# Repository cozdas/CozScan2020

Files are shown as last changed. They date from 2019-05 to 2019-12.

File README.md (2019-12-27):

# CozScan2020



This is a do-it-yourself 20-channel solid-state scanner card compatible with Keithley 2000-SCAN-20 and thus should work with Keithley 2000, 2001, 2002, 2010 and DMM6500 bench multimeters. **Currently this design is tested only on DMM6500.**

|**== Warning ==**|
|-|
| **If you decide to build and/or use this card do it at your own risk. I do not guarantee that this design works properly and I can't guarantee that using this won't result any damages to the equipment or won't cause injury. Electrical or thermal limits of this design are unknown/unspecified. So please make sure that you understand the design before attempting to build and/or use it.**|

## History behind the project
I've always had a multimeter since highschool, where I studied electronics. But all of them were handheld devices. So recently I decided to get a bench multimeter and Keithley DMM6500 seemed like a perfect choice for my needs. I liked the scanner card support which makes the unit work as a small data acqusition system. I bought a used 2000-SCAN card from eBay and it worked perfectly, I was able to record multiple quantities over long time spans and analyse their dependencies (such as tempco measurement ). But there was one problem: the original SCAN-2000 card has mechanical relays and they are loud therefore logging multiple channels overnight in my office, which is near our bedroom, was an annoying dripping-tap simulator. So I decided to build myself a silent solid-state version.

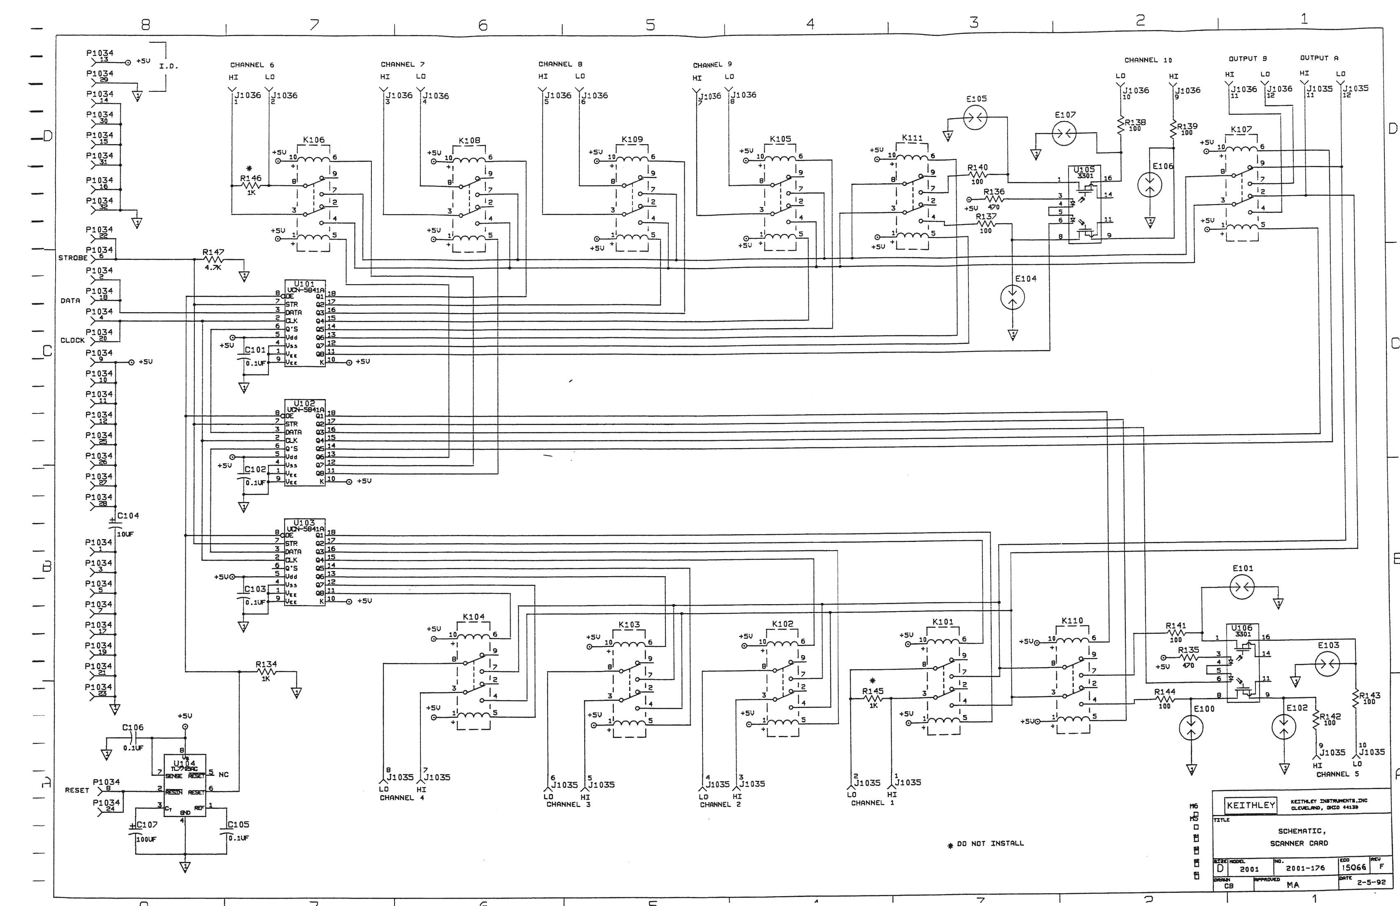
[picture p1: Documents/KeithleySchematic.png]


The original Keithley SCAN-2000 card has a very basic design: few serial-to-parallel shift registers and bunch of bi-stable (latching) mechanical relays. The control signal from the DMM has 3 lines: clock, data and strobe. The card's manual has the full schematic; by looking at the schematic you can determine which bit does what. After realizing that the 20-channel scan-2020 card uses the same interface and the same basic circuit design, I decided to implement a 20 channel card, the more the merrier. The DMM determines the installed card type using the ID pins (13 and 29) on the connector. 

## Reverse Engineering the Communication

The schematic shows all the connections and logic but doesn't tell much about the timings and how the DMM drives the relays. For that reason I just sniffed the clock, data and strobe lines both in scan-2000 and scan-2020 mode using both my oscillascope and a cheap logic analyser. You can find the [logic analyser logs](Documents/LogicAnalyserLogs/) in the Documents folder. You can open the files with [Saleae Logic software](https://www.saleae.com/downloads/)

Here are the key timing figures:

* Clock: 100kHz, %33 duty
* Data: 10us, centered around clock pulse
* Relay coil current duration: 4ms
* Strobe Pulse: 3.333ms
* Channel off to channel on: ~1.7ms

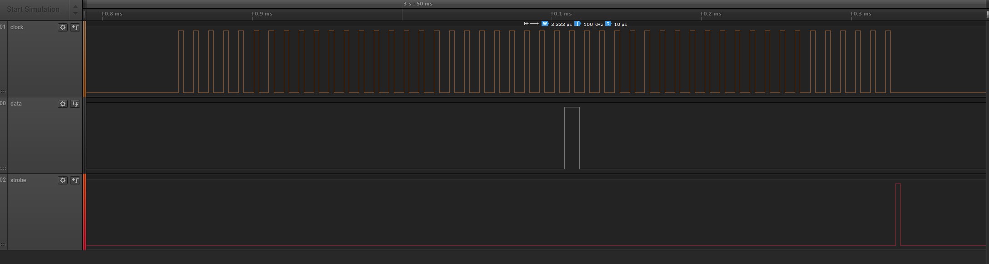
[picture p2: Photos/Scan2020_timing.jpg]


## Circuit Design

Initially I was planning to replicate the same circuit, using the same or similar components. One problem with that approach was that unlike the mechanical latching relays, the solid state relays are not latching thus I had add latches to the circuit so that the turned on relay stays on even after the DMM sets the coil off. This quickly increased the number of compoments required for the board. 

So instead of following the same design with primitive logic elements, I decided to switch to a microcontroller + software solution. I needed a cheap microcontroller with at least 25 IO pins (20 outputs for the channels, 2 outputs for directing the upper channels either to input or to sense and 3 input pins for DMM communication). The most convenient solution turned out to be using a cheap arduino micro compatible board with ATmega32U4 MCU. One minor problem with that board was that only 24 of the 26 IO pins of the ATmega32U4 were exposed on the board pinout and that was unfortunately 1 short of what I needed. But after checking the Arduino Micro schematic I saw that it's easy to pull a wire from the TX led to one of the unused pins, exposing PD5 signal and thus increasing the IO pin count to needed 25.

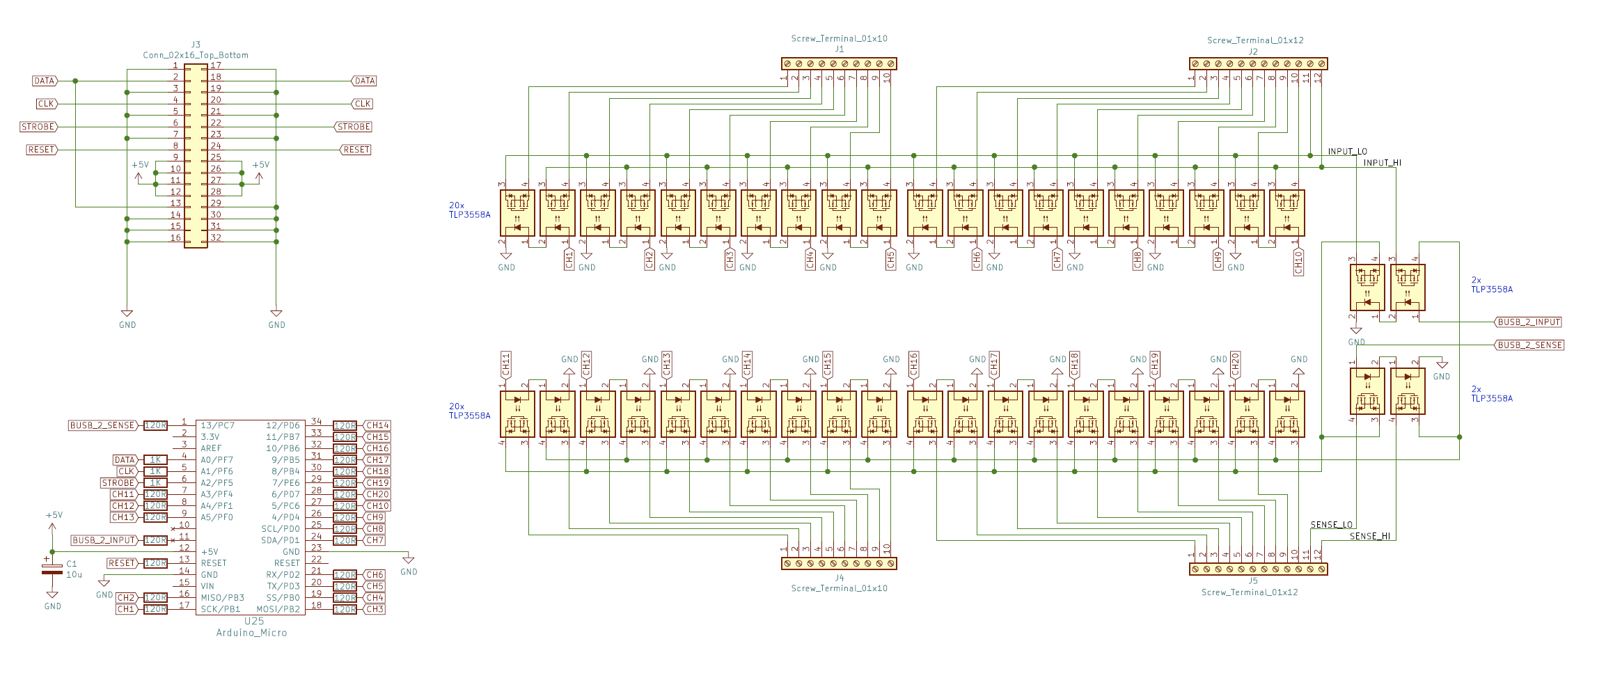
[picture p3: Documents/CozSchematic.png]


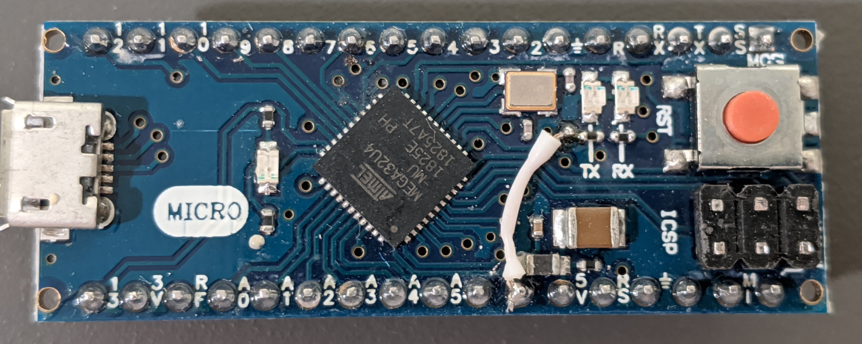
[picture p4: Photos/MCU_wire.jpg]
WIRE PIC


One gothca you need to be careful while choosing a MCU board is that some boards with certain bootloader firmware (Such as Arduino Uno) will blink the LED while booting. Make sure that the board+firmware you have doesn't have this behavior.

As SSRs I picked Toshiba TLP3558A as it seemed to be at the sweet spot of on-resistance, price and leakage current. It might not be the best choice, feel free to modify that to your taste.

## PCB Design
This is a "Do-It-Yourself as much as you can" project, thus I wanted to make my own PCB. Since I can't do through-hole plating I designed the layout such that the pins of the components are used as the vias and for this reason I preferred through-hole components. A more tidy and even compact layout with SMD components should be possible if the PCB will be manufactured professionally. First I tried to use Eagle CAD, which I was already familiar with, but the free version is not supporting boards this big. Internets(tm) seems to agree on the KiCAD as one of the best options, thus I learned how to use KiCAD and used it for this project.

You can find the KiCAD project files in the [KiCAD folder](KiCad/). Since this is my very first KiCAD design, I'm sure that there are some mistakes/not-so-correct things I've done. Let me know if you spot any.

## Software

My first attemp was an interrupt-driven software but it was behaving erratically. After a short debugging session I found the source of the problem: the MCU was not fast enough and was missing the clocks. I tried to optimize the code as much as I can with some bit-magic etc but it was still missing the clocks. So I decided to switch to active polling mode and disable the inturrupts completely, making the system more suitable for a realtime application. Polling the clock edges in an active loop indeed worked properly and it was fast enough that I was able to squeeze in some sanity checking routine to the code; making sure that we collected correct number of bits before the strobe, only one channel is connected to the input or sense terminals etc.

The Arduino studio source is located in the [Arduino](Arduino/) folder.

## Bill of Materials
- DMM Connector: 1x [Molex 85050](https://www.digikey.com/product-detail/en/molex/0850500000/WM20488-ND/2790645)
- Solid State Relay: 24x [Toshiba TLP3558A](https://www.digikey.com/product-detail/en/toshiba-semiconductor-and-storage/TLP3558A-F/TLP3558A-F-ND/8539925)
- Cable Terminal Blocks: 
  - 12 Pos: 2x [Phoenix Contact 1869318](https://www.digikey.com/product-detail/en/phoenix-contact/1869318/277-6361-ND/349230)
  - 10 Pos: 2x [Phoenix Contact 1869295](https://www.digikey.com/product-detail/en/phoenix-contact/1869295/277-6063-ND/349229)
- Controller: 1x [Arduino Micro](https://store.arduino.cc/usa/arduino-micro) (or [a clone](https://www.amazon.com/dp/B00J1X5B7Y))
- Resistors
  - 22x 120 Ohm 1/4W
  - 3x 1 kOhm 1/4W
- Capacitor: 1uF 16V
- PCB: 205mm x 70mm x 1.5mm, dual-sided

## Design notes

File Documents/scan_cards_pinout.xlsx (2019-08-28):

keithley pin # | Header Pin # | name | 2000-172 (my board) | 2001-176 revF | 2000-SCAN-20 | 2001-TSCAN | 1801 nanovolt preamp | wire
1 |  |  | GND | GND | GND | GND | GND | blue
2 |  | DATA | DATA | DATA | DATA | DATA | DATA | blue/white
3 |  |  | GND | GND | GND | GND | GND
4 |  | CLK | CLK | CLK | CLK | CLK | CLK | brown/white
5 |  |  | GND | GND | GND | GND | GND
6 |  | STROBE | STROBE | STROBE | STROBE | STROBE | STROBE | brown
7 |  |  | GND | GND | GND | GND | GND
8 |  | RESET | RESET | RESET | RESET | RESET | RESET | orange/white
9 |  |  | 5V | 5V | 5V | 5V | 5V
10 |  |  | 5V | 5V | 5V | 5V | 5V | orange
11 |  |  | 5V | 5V | 5V | 5V | 5V
12 |  |  | 5V | 5V | 5V | 5V | 5V
13 |  | ID | 5V | 5V | DATA | 5V | 5V | green
14 |  |  | GND | GND | GND | GND | SCL
15 |  |  | GND | GND | GND | GND | SDA
16 |  |  | GND | GND | GND | GND | GND
17 |  |  | GND | GND | GND | GND | GND
18 |  | DATA | DATA | DATA | DATA | DATA | DATA
19 |  |  | GND | GND | GND | GND | GND
20 |  | CLK | CLK | CLK | CLK | CLK | CLK
21 |  |  | GND | GND | GND | GND | GND
22 |  | STROBE | STROBE | STROBE | STROBE | STROBE | STROBE
23 |  |  | GND | GND | GND | GND | GND
24 |  | RESET | RESET | RESET | RESET | RESET | RESET
25 |  |  | 5V | 5V | 5V | 5V | 5V
26 |  |  | 5V | 5V | 5V | 5V | 5V
27 |  |  | 5V | 5V | 5V | 5V | 5V
28 |  |  | 5V | 5V | 5V | 5V | 5V
29 |  | ID | GND | GND | GND | GND | GND | green/white
30 |  |  | GND | GND | GND | GND | GND
31 |  |  | GND | GND | GND | GND | GND
32 |  |  | GND | GND | GND | GND | GND
Note: keithley numbers pins sequentially one row and moves on on the other row. Eagle uses row1, row2, row1, row2 order.

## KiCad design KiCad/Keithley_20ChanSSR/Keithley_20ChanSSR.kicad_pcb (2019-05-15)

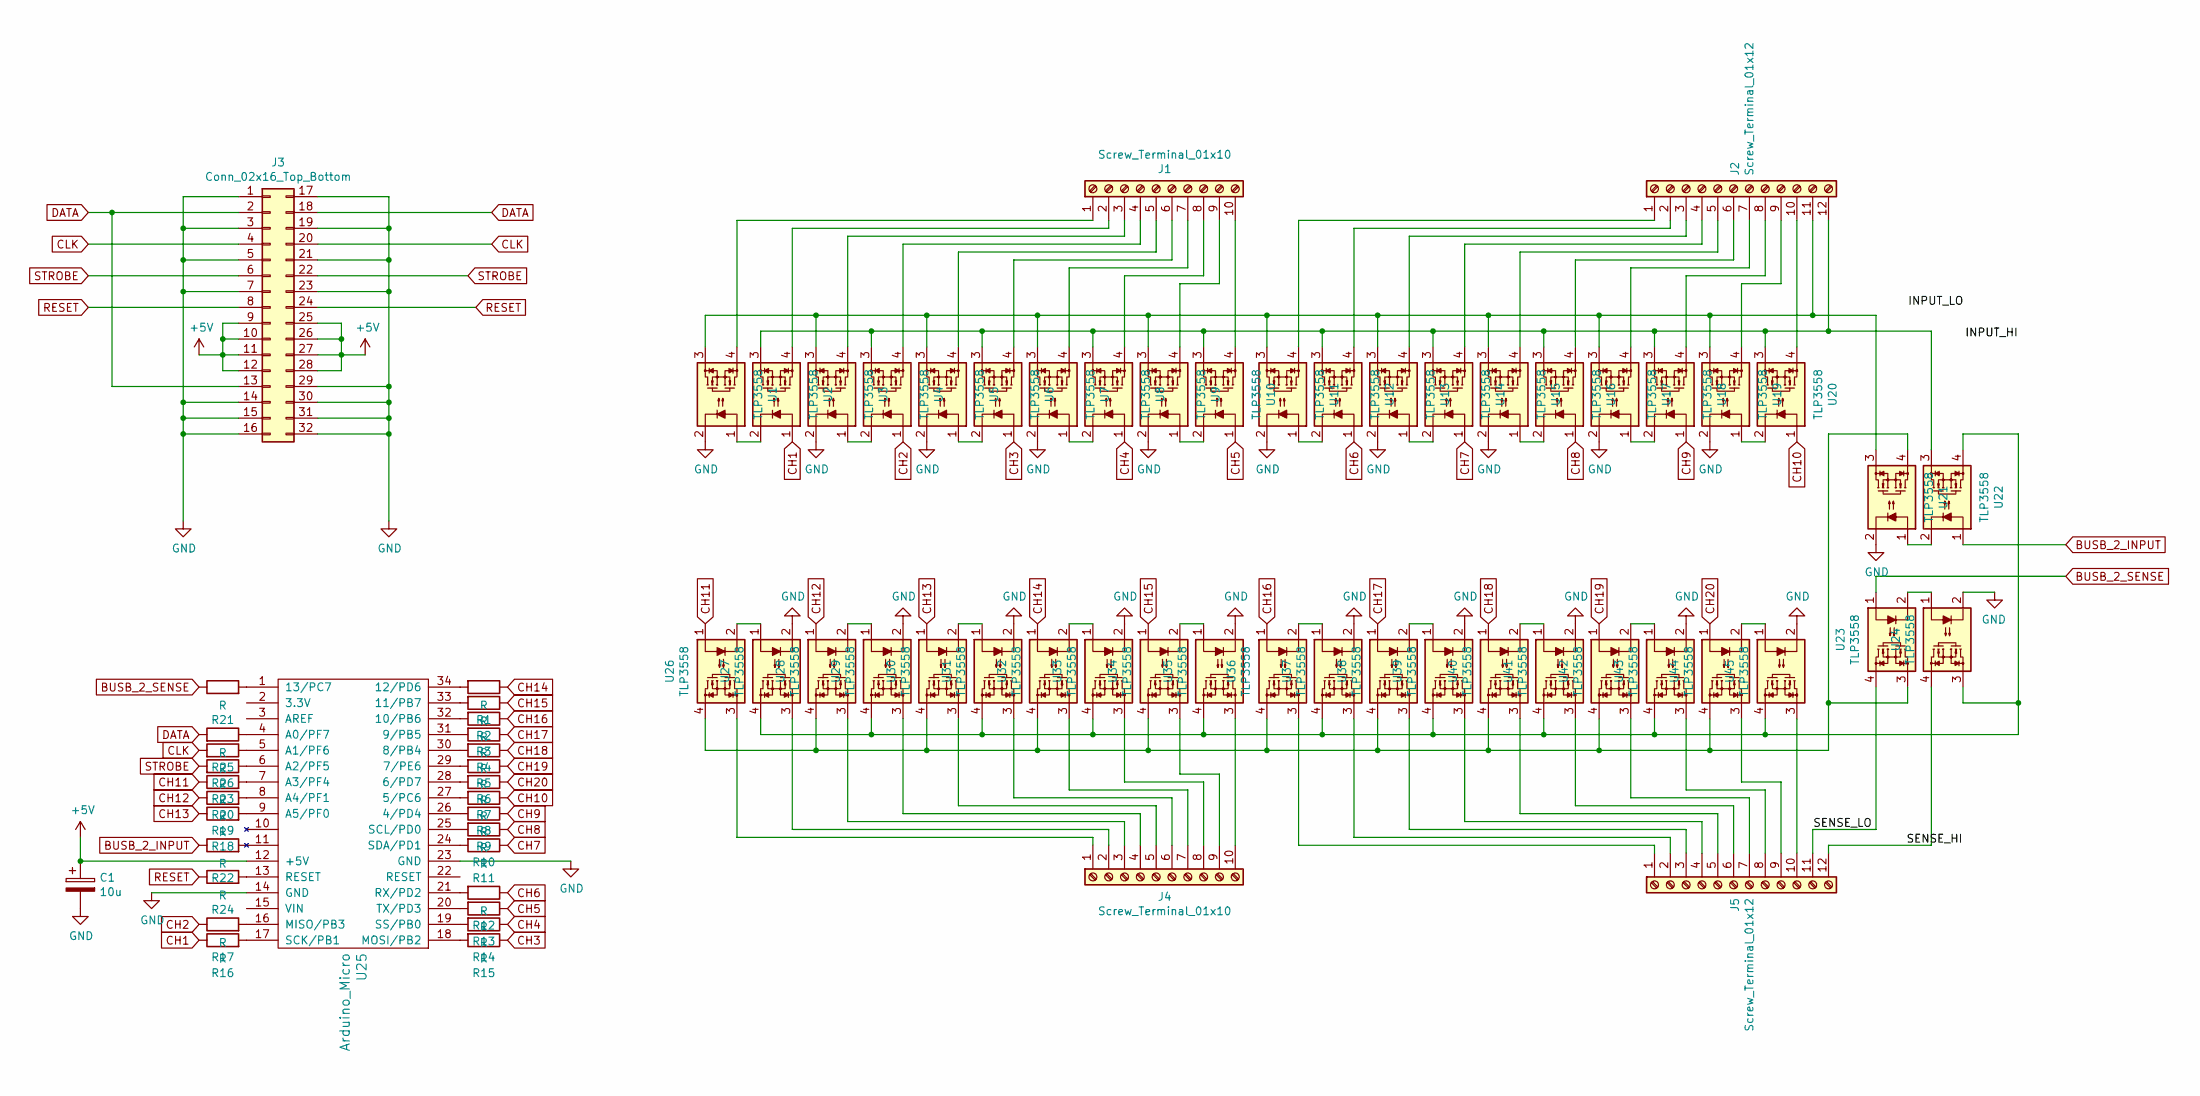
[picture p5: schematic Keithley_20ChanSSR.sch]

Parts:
C1: 10u; CP_EIA-6032-20_AVX-F
J1, J4: Screw_Terminal_01x10; TerminalBlock_Phoenix_MKDS-3-10-5.08_1x10_P5.08mm_Horizontal
J2, J5: Screw_Terminal_01x12; TerminalBlock_Phoenix_MKDS-1,5-12-5.08_1x12_P5.08mm_Horizon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
J3: Conn_02x16_Top_Bottom; DIN41612_B2_2x16_Horizontal
R1, R2, R3, R4, R5, R6, R7, R8, R9, R10, R11, R12, R13, R14, R15, R16, R17, R18, R19, R20, R21, R22, R23, R24, R25, R26: R; R_Axial_DIN0207_L6.3mm_D2.5mm_P10.16mm_Horizontal
U1, U2, U3, U4, U5, U6, U7, U8, U9, U10, U11, U12, U13, U14, U15, U16, U17, U18, U19, U20, U21, U22, U23, U24, U26, U27, U28, U29, U30, U31, U32, U33, U34, U35, U36, U37, U38, U39, U40, U41, U42, U43, U44, U45: TLP3558; DIP-4_W7.62mm_LongPads_coz
U25: Arduino_Micro; Arduino_Micro_Socket_coz

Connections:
+5V: C1.1, J3.9, J3.10, J3.11, J3.12, J3.25, J3.26, J3.27, J3.28, U25.12 (+5V)
/SENSE_LO: J5.11, U23.4
BUSB_2_INPUT: R22.1, U22.1
BUSB_2_SENSE: R21.1, U23.1
CH1: R16.1, U2.1
CH2: R17.1, U4.1
CH3: R15.1, U6.1
CH4: R14.1, U8.1
CH5: R13.1, U10.1
CH6: R12.1, U12.1
CH7: R11.1, U14.1
CH8: R10.1, U16.1
CH9: R9.1, U18.1
CH10: R8.1, U20.1
CH11: R20.1, U26.1
CH12: R19.1, U28.1
CH13: R18.1, U30.1
CH14: R1.1, U32.1
CH15: R2.1, U34.1
CH16: R3.1, U36.1
CH17: R4.1, U38.1
CH18: R5.1, U40.1
CH19: R6.1, U42.1
CH20: R7.1, U44.1
CLK: J3.4, J3.20, R26.2
DATA: J3.2, J3.13, J3.18, R25.2
GND: C1.2, J3.1, J3.3, J3.5, J3.7, J3.14, J3.15, J3.16, J3.17, J3.19, J3.21, J3.23, J3.29, J3.30, J3.31, J3.32, U1.2, U3.2, U5.2, U7.2, U9.2, U11.2, U13.2, U15.2, U17.2, U19.2, U21.2, U24.2, U25.14 (GND), U25.23 (GND), U27.2, U29.2, U31.2, U33.2, U35.2, U37.2, U39.2, U41.2, U43.2, U45.2
unnamed: J1.1, U1.4
unnamed: J1.2, U2.4
unnamed: J1.3, U3.4
unnamed: J1.4, U4.4
unnamed: J1.5, U5.4
unnamed: J1.6, U6.4
unnamed: J1.7, U7.4
unnamed: J1.8, U8.4
unnamed: J1.9, U9.4
unnamed: J1.10, U10.4
unnamed: J2.1, U11.4
unnamed: J2.2, U12.4
unnamed: J2.3, U13.4
unnamed: J2.4, U14.4
unnamed: J2.5, U15.4
unnamed: J2.6, U16.4
unnamed: J2.7, U17.4
unnamed: J2.8, U18.4
unnamed: J2.9, U19.4
unnamed: J2.10, U20.4
unnamed: J2.11, U1.3, U3.3, U5.3, U7.3, U9.3, U11.3, U13.3, U15.3, U17.3, U19.3, U21.3
unnamed: J2.12, U2.3, U4.3, U6.3, U8.3, U10.3, U12.3, U14.3, U16.3, U18.3, U20.3, U22.3
unnamed: J4.1, U26.3
unnamed: J4.2, U27.3
unnamed: J4.3, U28.3
unnamed: J4.4, U29.3
unnamed: J4.5, U30.3
unnamed: J4.6, U31.3
unnamed: J4.7, U32.3
unnamed: J4.8, U33.3
unnamed: J4.9, U34.3
unnamed: J4.10, U35.3
unnamed: J5.1, U36.3
unnamed: J5.2, U37.3
unnamed: J5.3, U38.3
unnamed: J5.4, U39.3
unnamed: J5.5, U40.3
unnamed: J5.6, U41.3
unnamed: J5.7, U42.3
unnamed: J5.8, U43.3
unnamed: J5.9, U44.3
unnamed: J5.10, U45.3
unnamed: J5.12, U24.4
unnamed: R1.2, U25.34 (12/PD6)
unnamed: R2.2, U25.33 (11/PB7)
unnamed: R3.2, U25.32 (10/PB6)
unnamed: R4.2, U25.31 (9/PB5)
unnamed: R5.2, U25.30 (8/PB4)
unnamed: R6.2, U25.29 (7/PE6)
unnamed: R7.2, U25.28 (6/PD7)
unnamed: R8.2, U25.27 (5/PC6)
unnamed: R9.2, U25.26 (4/PD4)
unnamed: R10.2, U25.25 (SCL/PD0)
unnamed: R11.2, U25.24 (SDA/PD1)
unnamed: R12.2, U25.21 (RX/PD2)
unnamed: R13.2, U25.20 (TX/PD3)
unnamed: R14.2, U25.19 (SS/PB0)
unnamed: R15.2, U25.18 (MOSI/PB2)
unnamed: R16.2, U25.17 (SCK/PB1)
unnamed: R17.2, U25.16 (MISO/PB3)
unnamed: R18.2, U25.9 (A5/PF0)
unnamed: R19.2, U25.8 (A4/PF1)
unnamed: R20.2, U25.7 (A3/PF4)
unnamed: R21.2, U25.1 (13/PC7)
unnamed: R22.2, U25.11
unnamed: R23.1, U25.6 (A2/PF5)
unnamed: R24.2, U25.13 (RESET)
unnamed: R25.1, U25.4 (A0/PF7)
unnamed: R26.1, U25.5 (A1/PF6)
unnamed: U1.1, U2.2
unnamed: U3.1, U4.2
unnamed: U5.1, U6.2
unnamed: U7.1, U8.2
unnamed: U9.1, U10.2
unnamed: U11.1, U12.2
unnamed: U13.1, U14.2
unnamed: U15.1, U16.2
unnamed: U17.1, U18.2
unnamed: U19.1, U20.2
unnamed: U21.1, U22.2
unnamed: U21.4, U23.3, U26.4, U28.4, U30.4, U32.4, U34.4, U36.4, U38.4, U40.4, U42.4, U44.4
unnamed: U22.4, U24.3, U27.4, U29.4, U31.4, U33.4, U35.4, U37.4, U39.4, U41.4, U43.4, U45.4
unnamed: U23.2, U24.1
unnamed: U26.2, U27.1
unnamed: U28.2, U29.1
unnamed: U30.2, U31.1
unnamed: U32.2, U33.1
unnamed: U34.2, U35.1
unnamed: U36.2, U37.1
unnamed: U38.2, U39.1
unnamed: U40.2, U41.1
unnamed: U42.2, U43.1
unnamed: U44.2, U45.1
RESET: J3.8, J3.24, R24.1
STROBE: J3.6, J3.22, R23.2

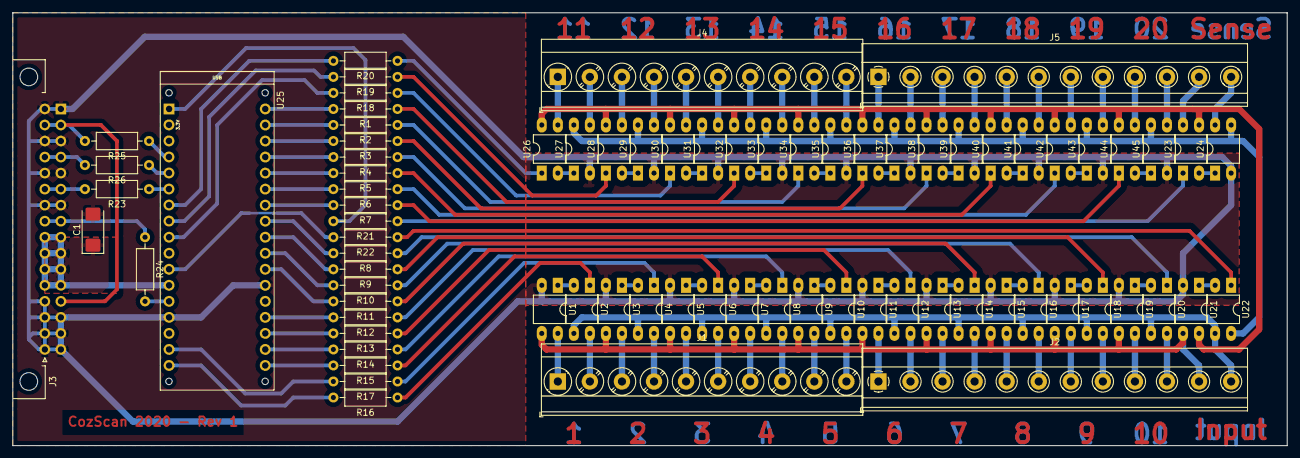
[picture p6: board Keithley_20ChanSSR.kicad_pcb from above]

Board: 2 copper layers, 201.9 x 68.6 mm, 77 parts (0 on the bottom side), 122 nets.

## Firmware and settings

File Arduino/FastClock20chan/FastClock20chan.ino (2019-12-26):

//===================
// CozScan2020
//===================

/* *****
BSD 3-Clause License

Copyright (c) 2019, Cuneyt Ozdas
All rights reserved.

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
1. Redistributions of source code must retain the above copyright notice, this
   list of conditions and the following disclaimer.

2. Redistributions in binary form must reproduce the above copyright notice,
   this list of conditions and the following disclaimer in the documentation
   and/or other materials provided with the distribution.

3. Neither the name of the copyright holder nor the names of its
   contributors may be used to endorse or promote products derived from
   this software without specific prior written permission.

THIS SOFTWARE IS PROVIDED BY THE COPYRIGHT HOLDERS AND CONTRIBUTORS "AS IS"
AND ANY EXPRESS OR IMPLIED WARRANTIES, INCLUDING, BUT NOT LIMITED TO, THE
IMPLIED WARRANTIES OF MERCHANTABILITY AND FITNESS FOR A PARTICULAR PURPOSE ARE
DISCLAIMED. IN NO EVENT SHALL THE COPYRIGHT HOLDER OR CONTRIBUTORS BE LIABLE
FOR ANY DIRECT, INDIRECT, INCIDENTAL, SPECIAL, EXEMPLARY, OR CONSEQUENTIAL
DAMAGES (INCLUDING, BUT NOT LIMITED TO, PROCUREMENT OF SUBSTITUTE GOODS OR
SERVICES; LOSS OF USE, DATA, OR PROFITS; OR BUSINESS INTERRUPTION) HOWEVER
CAUSED AND ON ANY THEORY OF LIABILITY, WHETHER IN CONTRACT, STRICT LIABILITY,
OR TORT (INCLUDING NEGLIGENCE OR OTHERWISE) ARISING IN ANY WAY OUT OF THE USE
OF THIS SOFTWARE, EVEN IF ADVISED OF THE POSSIBILITY OF SUCH DAMAGE.
***** */


// Notes:
// ==========
// using interrupts was too slow, the clock ISR was
// totally missing the data. Actively waiting the rising clock
// edge is much faster, now the data is properly sampled before the falling edge
// of the clock


//Arduino DATA pins on the Micro board
//D0 = pin 20  RX
//D1 = pin 21  TX
//D2 = pin 24  D2
//D3 = pin 25  D3
//D4 = pin 26  D4
//D5 = pin 27  D5
//D6 = pin 28  D6
//D7 = pin 29  D7
//D8 = pin 30  D8
//D9 = pin 31  D9
//D10 = pin 32 D10
//D11 = pin 33 D11
//D12 = pin 34 D12
//D13 = pin 1  D13
//D14 = pin16  MISO 
//D15 = pin17  SCK
//D16 = pin18  MOSI
//D17 = pin19  SS (RX LED)
//D18 = pin4   A0
//D19 = pin5   A1
//D20 = pin6   A2
//D21 = pin7   A3
//D22 = pin8   A4
//D23 = pin9   A5
//D24 = pin26  D4 ***duplicate***
//D25 = pin28  D6 ***duplicate***
//D26 = pin30  D8 ***duplicate***
//D27 = pin31  D9 ***duplicate***
//D28 = pin32  D10 ***duplicate***
//D29 = pin34  D12 ***duplicate***
//D30 = TXLED  --

/* SCAN CHANNEL TO PIN MAPPING
chan DPin   NAME  PORT    BIT   MicroPin
0     --, 
1     15    PB1   PORTB   1     17  B:1320 D:32104 C:6 
2     14    PB3   PORTB   3     16
3     16    PB2   PORTB   2     18
4     17    PB0   PORTB   0     19
5     1     PD3   PORTD   3     21
6     0     PD2   PORTD   2     20
7     2     PD1   PORTD   1     24
8     3     PD0   PORTD   0     25
9     4     PD4   PORTD   4     26
10    5     PC6   PORTC   6     27

11    21    PF4   PORTF   4     7   B:7654 C: D:67 E:6 F:410 
12    22    PF1   PORTF   1     8
13    23    PF0   PORTF   0     9
14    12    PD6   PORTD   6     34
15    11    PB7   PORTB   7     33
16    10    PB6   PORTB   6     32
17    9     PB5   PORTB   5     31
18    8     PB4   PORTB   4     30
19    7     PE6   PORTE   6     29
20    6     PD7   PORTD   7     28

21    13    PC7   PORTC   7     1
22    30    PD5   PORTD   5     (11: wire from TX led)
*/

/* CONTROL BIS TO CHANNEL AND PIN MAPPINGS
//first sent bit is MSB (bit48), last sent bit is LSB (bit0)
//even bits: reset coil
//odd bits: set coil
//ctrl bit, chan, Dpin, PORTBIT,  PORT,   BIT
0           11    21    PF4       PORTF   4
2           12    22    PF1       PORTF   1
4           13    23    PF0       PORTF   0
6           14    12    PD6       PORTD   6
8           15    11    PB7       PORTB   7
10          16    10    PB6       PORTB   6
12          17    9     PB5       PORTB   5
14          18    8     PB4       PORTB   4
16          19    7     PE6       PORTE   6
18          20    6     PD7       PORTD   7
20          1     15    PB1       PORTB   1
22          2     14    PB3       PORTB   3 
24          3     16    PB2       PORTB   2
26          4     17    PB0       PORTB   0
28          5     1     PD3       PORTD   3
30          6     0     PD2       PORTD   2
32          7     2     PD1       PORTD   1
34          8     3     PD0       PORTD   0
36          9     4     PD4       PORTD   4
38          10    5     PC6       PORTC   6
40          21    13    PC7       PORTC   7 //4WIRE
*/

//temp variables to hold register set/clear bits
uint8_t _PB, _PC, _PD, _PE, _PF;

const uint8_t PortMaskB = 0xFF; //8
const uint8_t PortMaskC = 0xC0; //2
const uint8_t PortMaskD = 0xFF; //8
const uint8_t PortMaskE = 0x40; //1 
const uint8_t PortMaskF = 0x13; //3 = total 22 bits

//mapping from scanner control bits to MCU registers (2 bits per entry, first bit clear, second set)
uint8_t* controlbit2port[]    = {&_PF,&_PF,&_PF,&_PD,&_PB,&_PB,&_PB,&_PB,&_PE,&_PD,&_PB,&_PB,&_PB,&_PB,&_PD,&_PD,&_PD,&_PD,&_PD,&_PC,&_PC};
uint8_t  controlbit2portbit[] = {   4,   1,   0,   6,   7,   6,   5,   4,   6,   7,   1,   3,   2,   0,   3,   2,   1,   0,   4,   6,   7};

//channel number to Arduino digital pin mapping. Note the scanner card starts from chan1 not 0
uint8_t Chan2Pin[]            = {99 ,15 ,14 ,16 ,17 ,1  ,0  ,2  ,3  ,4  ,5  ,21 ,22 ,23 ,12 ,11 ,10 ,9  ,8  ,7  ,6  ,13 ,30};

//control bits are shifted into this 64bit variable
uint64_t  state = 0;
uint8_t   numBitsCollected = 0;


void TestRun()
{
  delay(5000);

  for(;;)
  {
    //reset chan 21, this will connect bus_b to intput
    state = 1ll<<40;
    numBitsCollected = 48;
    strobe();

    //connect all channels to input one by one
    for(int i=0;i<20;++i)
    {
      //close relay
      state = 1ll<<(2*i+1);
      numBitsCollected = 48;
      strobe();
      delay(250);

      //open relay
      state = 1ll<<(2*i);
      numBitsCollected = 48;
      strobe();
      delay(50);
    }
  }
}

//return true if internal relay states makes sense
bool SanityCheck(uint32_t busA, uint32_t busB )
{
  //check if busses have more than 1 bit set  
  bool tooManyBitsInA = busA & (busA-1); //this op clears the rightmost 1 bit. if result is nonzero, then more than one bit was set 
  bool tooManyBitsInB = busB & (busB-1); //this op clears the rightmost 1 bit. if result is nonzero, then more than one bit was set 

  if(tooManyBitsInA | tooManyBitsInB)
    return false;
    
  bool busBtoSense  = _PC&(1<<7);
  bool busBtoIn     = _PD&(1<<5);

  //bus B should be connected to either In or sense
  if(busBtoSense && busBtoIn)
    return false;

  //now make sure that if both busA and busB has connected channels, then the busB should not connect to input (4-wire should be on)
  if(busA && busB && !busBtoSense)
    return false;

  //passed all checks
  return true;
}

//we process the bits in two passes to guarantee the "break before connect" ordering.
//pass1: read the odd bits, which are reset coil commands, and clear the corresponding port bits for those channels
//pass2: read the even bits, which are set coil commands, and set the corresponding port bits for those channels
//(heavy bit manipulation for fastest write)
void strobe()
{
  //we can safely ignore the coil deenergizing events
  if(state==0)
    return;

  //we are out of sync if strobe comes not after exactly 48 bits. 
  //Disconnect everything to be on the safer side
  /*
  if(numBitsCollected!=48)
  {
    PORTB = PORTC = PORTD = PORTE = PORTF =0; 
    return;
  }
  */

  //disconnect everything
  PORTB &= ~PortMaskB;
  PORTC &= ~PortMaskC;
  PORTD &= ~PortMaskD;
  PORTE &= ~PortMaskE;
  PORTF &= ~PortMaskF;  

  //Pass0: process the reset bits (even bits)
  {
    uint64_t st = state;
    for(int i=0; i<21; ++i, st>>=2)
    {
      (*controlbit2port[i]) &= ~((st&1)<<(controlbit2portbit[i]));
    }

    //also if the SENSE connection is set, break the INPUT connection now
    //if(state&(1ll<<41))
    //  PORTD &= ~(1<<5);
  }

  //Pass1:  process the set bits (odd bits)
  {
    uint64_t st = state>>1;
    for(int i=0; i<21; ++i, st>>=2)
    {
      (*controlbit2port[i]) |= (st&1)<<(controlbit2portbit[i]);
    }

    //BusB2In = !BusB2Sense (PD5 = !PC7)
    //_PD = (PD&~(1<<5)) | (((~_PC)&(1<<7))>>2);
    if(_PC&(1<<7))
      _PD &= ~(1<<5);
    else 
      _PD |= (1<<5);

    //arbitrarily arranged bitmap of each bus for bit counting (busA: chan 1..10, busB: chan 11..20)
    uint32_t busA = (_PB & 0x0Fl) | ((_PC & 0x40l)<<8) | ((_PD & 0x1Fl)<<16);                                            //chans 1..10
    uint32_t busB = (_PB & 0xF0l) |                     ((_PD & 0xC0l)<<8)  | ((_PE & 0x40l)<<16) | ((_PF & 0x13l)<<24);   //chans 11..20

    if(SanityCheck(busA, busB))
    {   
      PORTB |= _PB;
      PORTE |= _PE;
      PORTF |= _PF;

      //if no channel is active on BusB, then let BusB dangle (reduces leakage between BusA and BusB channels)
      if(busB)
      {
        PORTC |= _PC;
        PORTD |= _PD;
      }
      else
      {
        PORTC |= (_PC & ~(1<<7));
        PORTD |= (_PD & ~(1<<5));       
      }
    }
  }
  
  state = 0;  
  numBitsCollected = 0;
}

void setup() 
{
  //Serial.begin(115200);
  //set all channel pins to output
  for(int i=1; i<23; ++i)
  {
    pinMode(Chan2Pin[i], OUTPUT);
    digitalWrite(Chan2Pin[i], LOW);
  }

  //set the input pins
  pinMode(18, INPUT); //A0: PF7: DATA
  pinMode(19, INPUT); //A1: PF6: CLOCK
  pinMode(20, INPUT); //A2: PF5: STROBE

  //port states
  _PB = _PC = _PD = _PE = _PF = 0;

  state = 0;  
  numBitsCollected = 0;

  //TestRun();
}

//active waiting the pin states is much faster than interrupt driven system
//busy waiting the clocks and strobe there in a very thight loop
void loop() 
{
  //cli(); //disabling interrupts right away causes the Arduino IDE fail to upload the sketch.

  while(1)
  {
    //wait rising edge of the clock
    while(!(PINF&(1<<6)))
    {
      //while waiting check strobe rising edge
      if(PINF&(1<<5)) 
      {
        strobe();
        //don't need to wait strobe signal's falling edge, even if strobe retriggers, since state will be 0, it'll return immediately 
      }
    }

    //we delay disabling interrupts because if this executes right away the 
    //uploader can't upload (probably verify) the sketch thus giving error during upload.
    //I'm guessing that the sketch runs before the verify begins and when interrupts are disabled
    //USB doesn't work.
    cli();  
    
    //sample
    uint8_t b = ((PINF>>7)&1);
    state = (state<<1) | b;
    numBitsCollected++;
    
    //wait falling clock edge
    while(PINF&(1<<6));
  }
}

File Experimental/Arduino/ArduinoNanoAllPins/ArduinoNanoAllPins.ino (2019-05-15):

void setup() 
{
  pinMode(0, OUTPUT);   //CH1
  pinMode(1, OUTPUT);   //CH2
  pinMode(2, OUTPUT);   //CH1
  pinMode(3, OUTPUT);   //CH2
  pinMode(4, OUTPUT);   //CH1
  pinMode(5, OUTPUT);   //CH1
  pinMode(6, OUTPUT);   //CH2
  pinMode(7, OUTPUT);   //CH3
  pinMode(8, OUTPUT);   //CH4
  pinMode(9, OUTPUT);   //CH5
  pinMode(10, OUTPUT);  //CH6
  pinMode(11, OUTPUT);  //CH7
  pinMode(12, OUTPUT);  //CH8
  pinMode(13, OUTPUT);  //CH8
  
  pinMode(A0, OUTPUT);  //CH9
  pinMode(A1, OUTPUT);  //CH9
  pinMode(A2, OUTPUT);  //CH10
  pinMode(A3, OUTPUT);  //OUTB->A
  pinMode(A4, OUTPUT);  //OUTB->B
  pinMode(A5, OUTPUT);  //OUTB->B
  pinMode(A6, OUTPUT);  //OUTB->B
  pinMode(A7, OUTPUT);  //OUTB->B
}

void loop() 
{
  digitalWrite(0, HIGH);
  digitalWrite(1, HIGH);
  delay(250);
  digitalWrite(0, LOW);
  digitalWrite(1, LOW);
  delay(250);

}

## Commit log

2019-05-15 - First version of CozScan2020 card and the arduino Micro code to drive the relays. Seems working fine
    [KeithleySSRScanCard.sch, Keithley_20ChanSSR.kicad_pcb, Keithley_20ChanSSR.sch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]
2019-08-26 - reworked the logic in the strobe call to have the system more robust. - Added sanity checks to strobe making sure that not two channels are connected to a single bus - if no channels on Bus B are t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
    [FastClock20chan.ino]
2019-08-28 shuffled files around for cleaner organization
    [KeithleySSRScanCard.sch, scan_cards_pinout.xlsx]
2019-12-26 Deleted some unused files, added the required library.
    [Keithley_20ChanSSR.sch, Keithley_20ChanSSR_take2.kicad_pcb, Keithley_20ChanSSR_take3.kicad_pcb]
2019-12-26 more work on readme, moved doc files around
    [scan_cards_pinout.xlsx]
2019-12-26 updated readme, added schematics, removed eagle files
    [KeithleySSRScanCard.sch]
2019-12-27 Cleaned up the schematic for better readibility
    [Keithley_20ChanSSR.sch]
2019-12-27 updated the BOM
